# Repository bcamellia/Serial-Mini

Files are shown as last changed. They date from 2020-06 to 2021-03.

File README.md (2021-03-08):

Not actively developing, still wish to revisit at some point.

Serial Mini is an original rework of my PS/2 mini keyboard to further reduce input latency. It sends keystrokes using RS232 at up to a 115k baud rate. The keystrokes are processed and registered by a Linux kernel driver. The driver first converts a TTY line into a serial port object, connects the serial keyboard, and registers keystrokes using an interrupt. Using this method, I could achieve a round-trip latency of up to ~0.5ms.

Features:
* Bootloader support (in-development)
* Integrated MAX232 (in-development)
* Hardware based switch debouncing
* RBG Backlighting with controls (in-development)

To-do:
* Remove unused libraries
* Double check connections
* Add measurements and example video
* Write firmware without using CCS

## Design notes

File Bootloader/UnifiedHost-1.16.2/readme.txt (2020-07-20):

# README	General information
* Unified Bootloader Host Application 
- Used with the MCC Bootloader Generated Software Library for 8-bit or 16-bit MCU devices, or the 32-bit AN1388 bootloader.
- The graphical front-end of the 8-bit, 16-bit and 32-bit Bootloader project.

# Support
Email: MCC_Support@microchip.com
This application requires the Java 1.8 runtime.
Users of Microchip products can receive assistance through several channels:

 - Distributor or Representative
 - Local Sales Office
 - Field Application Engineer (FAE)
 - Technical Support

Customers should contact their distributor, representative or Field Application Engineer (FAE) for support.
Local sales offices are also available to help customers.
A listing of sales offices and locations may be found on the [Microchip web site][3].

Technical support is available through the [Microchip web site][4].

# CHANGELOG	A detailed changelog, intended for programmers
v 0.1.9:	Added readme, added logger, added checksum support to PIC32; added handling for record type 0x05 (currently ignored)
v 0.1.10:	Internal release
v 0.1.11:	Internal release
v 0.1.14:	Added PIC32 CRC bytes used at end of packets. Added Erase feature to USB PIC32 command chain. Extended Timeouts added support for 24-bit packet length.
v 0.1.15:	Fixed bug in PIC16 erase being half expected length during command chain. Added support for larger PIC18 device checksum commands, appending over previous Access Key bytes.
v 1.0.0:	Release version to support PIC24 family of devices. Added beta support for AVR devices.
v 1.15.0:   Release version to support dsPIC33 family of devices. Release support for AVR devices.
v 1.15.1:   Fixed bugs to support PIC-IOT WG Development Board, phantom byte for degenerate blocks and restrict data packet size to MAX_PACKET_SIZE - HEADER_SIZE.
v 1.16.1:   Updated HID4JAVA library used for USB communication. Updates to AVR support to support MCC generated code. Extended PIC32 timeout(s) to 20s (from 8) UDP, USB
v 1.16.2:   32-bit devices no longer wait for responds from Reset Command. Bugfixes for 16-bit support: 1) Self Verify issue with larger parts with 2) no report, 3) End Address corruption on read properties, 4) Exception thrown on UART disconnect.

# NEWS	A basic changelog, intended for users
-Incremented version information; see Changelog
-Added readme file on release of version: 0.1.14
-Added Checksum support for PIC32
-Bug fixes, Added Release Notes v 0.1.15 along with readme file. Added support for up to 32-bit checksum value calculation.
-Added Synch Byte expectation to AVR packet support.
-Fixed Typo in Help-->About text which indicated incorrect Utility version
-Added logger support requires launching from command prompt with below text:
* -Djava.util.logging.config.file="C:\<DirectoryLocation>"

i.e.: To Launch from Command Prompt
>java -Djava.util.logging.config.file="<Drive: e.g. C>:\<MyDirectory>\<UnifiedHost-version>\logging.properties" -jar UnifiedHost-<version>.jar

# INSTALL	Installation instructions
Installation of Java JRE

# COPYING / LICENSE	Copyright and licensing information
See LICENSE.txt for licensing information.

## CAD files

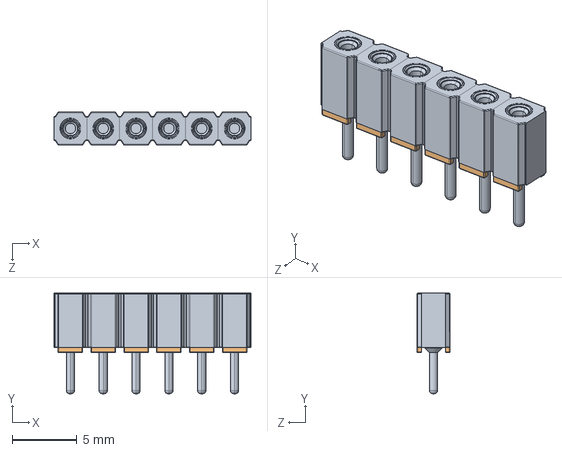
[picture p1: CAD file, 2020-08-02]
Hardware/models/801-xx-006-10-012000.STEP
15.2 x 7.78 x 2.54 mm

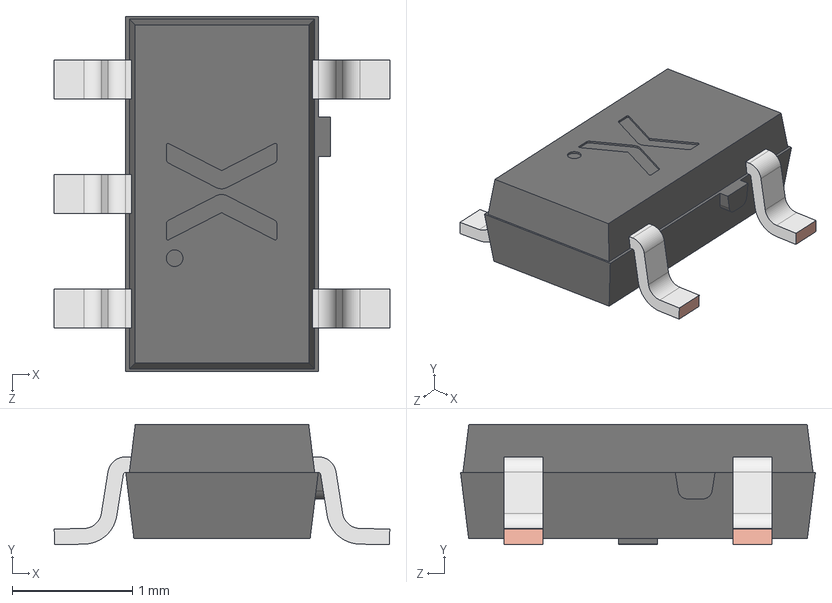
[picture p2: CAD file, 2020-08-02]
Hardware/models/SOT753.step
2.79 x 1.00 x 2.95 mm
SOT753 Lower mold body
SOT753 Lead x 5
SOT753 Upper mold body

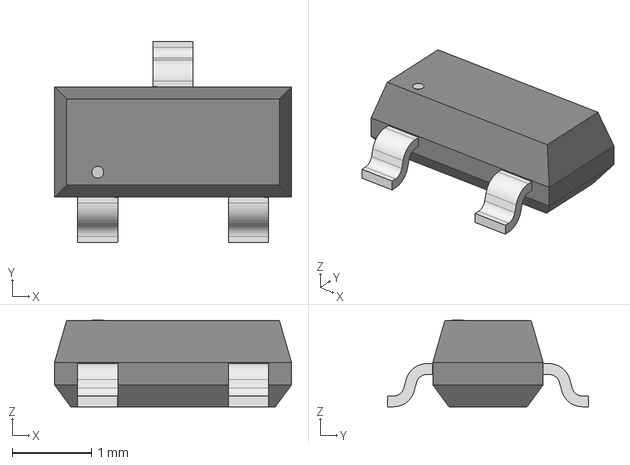
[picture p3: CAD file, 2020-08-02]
Hardware/models/SOT23_INF.step
3.00 x 2.54 x 1.09 mm

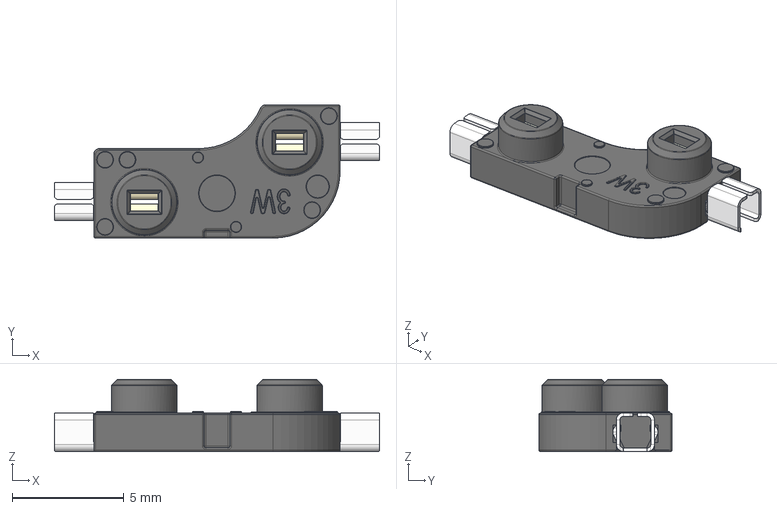
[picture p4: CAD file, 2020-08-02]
Hardware/models/Kailh Hotswap MX v22.step
14.5 x 5.95 x 3.22 mm

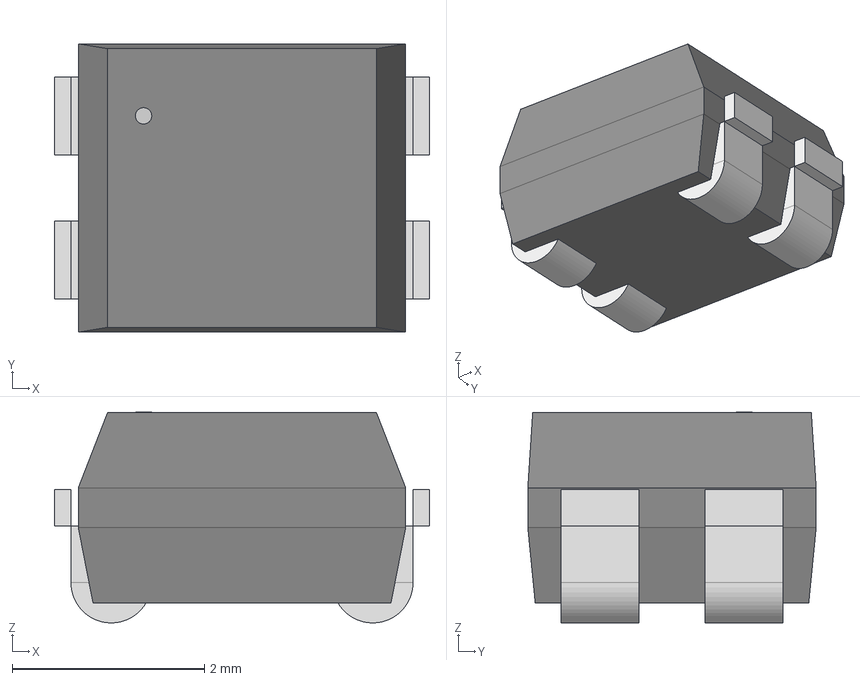
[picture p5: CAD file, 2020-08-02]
Hardware/models/BOX_7R3R3.step
3.90 x 3.00 x 2.19 mm

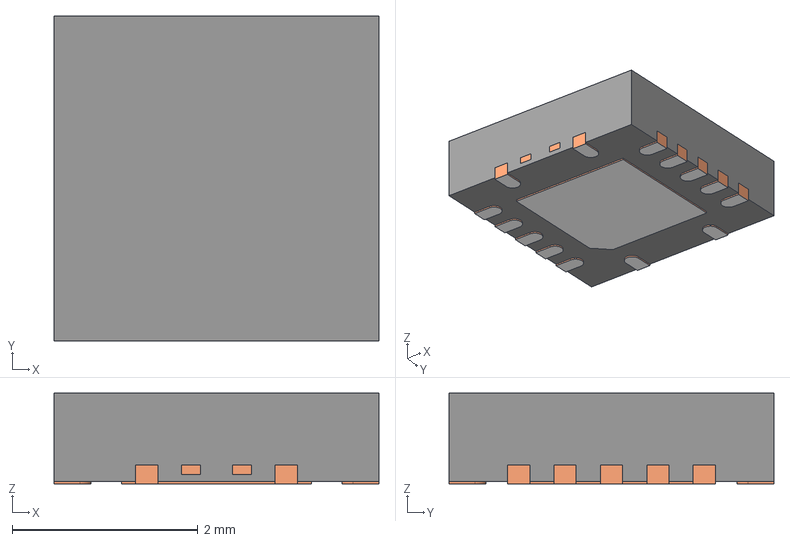
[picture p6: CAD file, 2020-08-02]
Hardware/models/RGY0014A.stp
3.50 x 3.50 x 0.975 mm
BODY-QFN
FRAME-RWA0014A
PIN1-ID

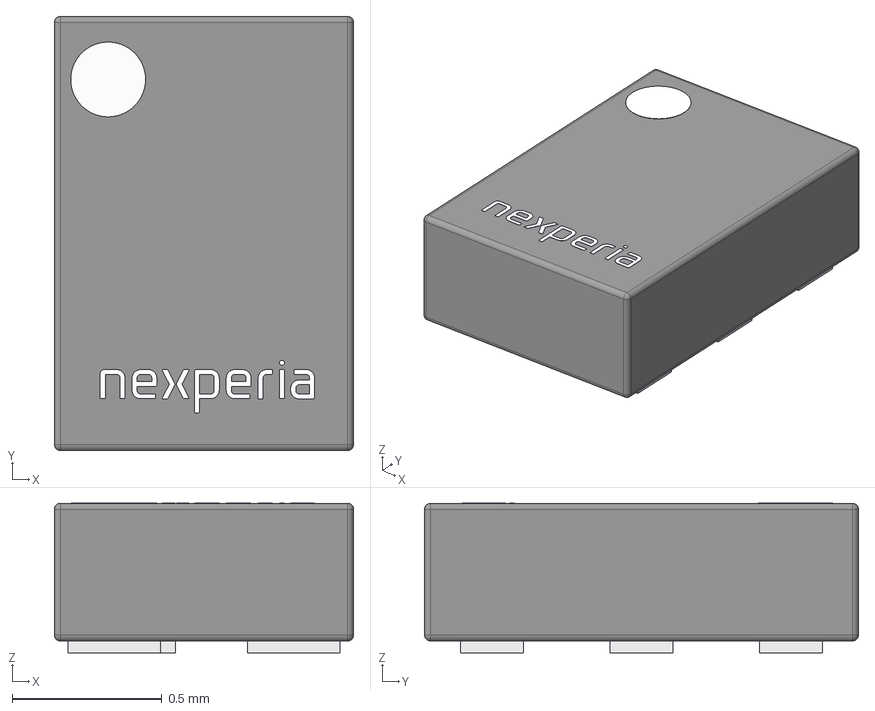
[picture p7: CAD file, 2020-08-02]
Hardware/models/Nexperia_-_PRTR5V0U2F,115.step
1.00 x 1.45 x 0.501 mm
Boady
Leads
Nexperia
circle

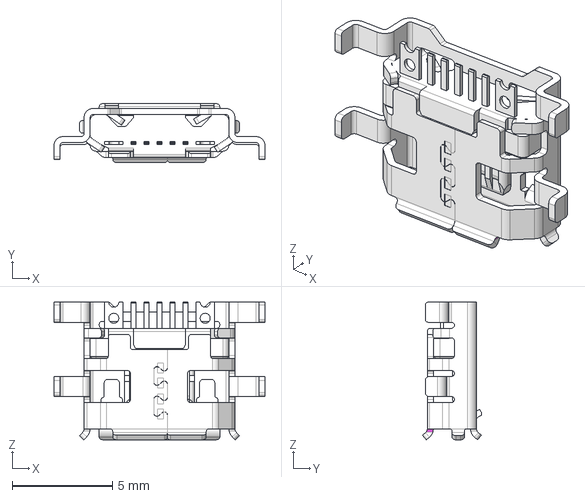
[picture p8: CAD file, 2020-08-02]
Hardware/models/10103593-0001lf.stp
10.5 x 2.94 x 6.85 mm

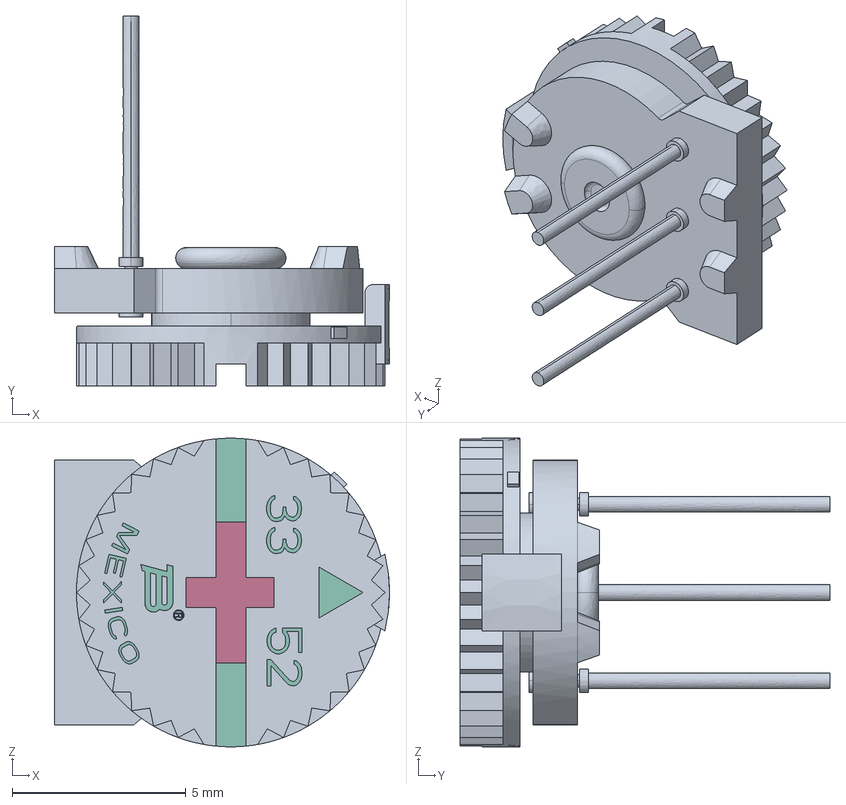
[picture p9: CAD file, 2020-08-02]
Hardware/models/3352T001XXX.stp
9.65 x 10.7 x 8.89 mm

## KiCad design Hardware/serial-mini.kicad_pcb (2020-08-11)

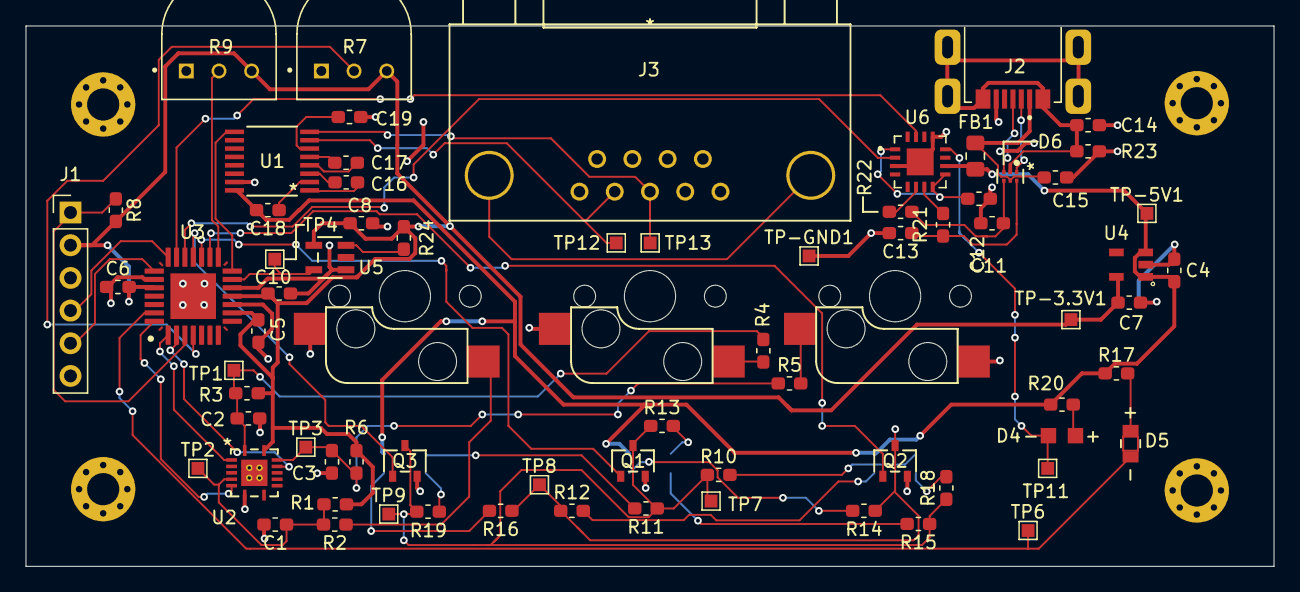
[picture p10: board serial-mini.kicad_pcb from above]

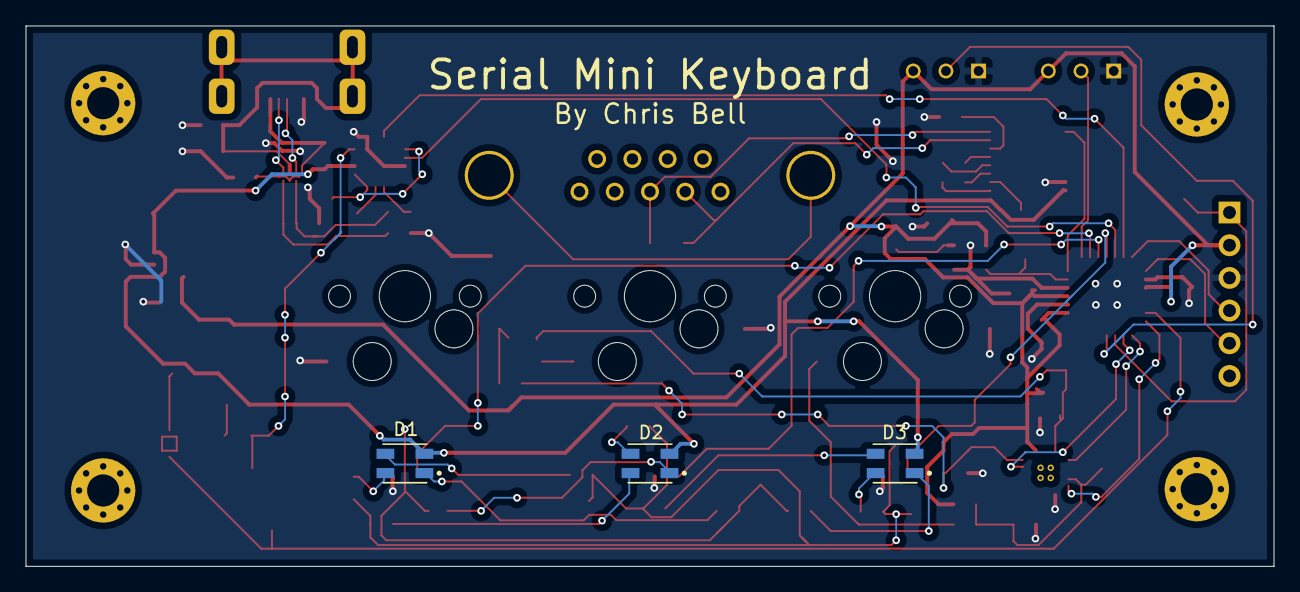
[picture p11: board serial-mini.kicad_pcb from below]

Board: 4 copper layers, 97.0 x 42.0 mm, 82 parts (3 on the bottom side), 58 nets.

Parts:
C1, C2, C3, C15: 10nF; C_0603_1608Metric_Pad1.05x0.95mm_HandSolder
C4, C7: 1UF; C_0603_1608Metric_Pad1.05x0.95mm_HandSolder
C5, C6, C8, C10: 0.1UF; C_0603_1608Metric_Pad1.05x0.95mm_HandSolder
C11: 0.1uF; C_0603_1608Metric_Pad1.05x0.95mm_HandSolder
C12, C13: 47pF; C_0603_1608Metric_Pad1.05x0.95mm_HandSolder
C14: 4.7nF; C_0603_1608Metric_Pad1.05x0.95mm_HandSolder
C16, C17, C18, C19: 1uF; C_0603_1608Metric_Pad1.05x0.95mm_HandSolder
D1, D2, D3: CLVBA-FKA; SOL150P350X210-4N
D4: LTST-C171KSKT; DIOC200X125X110
D5: VAOL-S8WR4
D6: PRTR5V0U2F,115; Nexperia-SOT886-11_2018-0-MFG
FB1: MI0805K601R; R_0805_2012Metric_Pad1.15x1.40mm_HandSolder
H1, H2, H3, H4: MountingHole; MountingHole_2.5mm_Pad_Via
J1: 801-47-006-10-012000; PICKITv3
J2: 10103593-0001LF; AMPHENOL_10103593-0001LF
J3: 3-106505-2
Q1, Q2, Q3: IRLML2060; IRLML2060TRPBF
R1, R3, R6, R8, R24: 10k; R_0603_1608Metric_Pad1.05x0.95mm_HandSolder
R2, R4, R5: 1k; R_0603_1608Metric_Pad1.05x0.95mm_HandSolder
R7, R9: 3352T-1-103LF; TRIM_3352T-1-103LF
R10, R11, R13, R15, R17, R18, R19: 100; R_0603_1608Metric_Pad1.05x0.95mm_HandSolder
R12, R14, R16, R20: 150; R_0603_1608Metric_Pad1.05x0.95mm_HandSolder
R21, R22: 27; R_0603_1608Metric_Pad1.05x0.95mm_HandSolder
R23: 1M; R_0603_1608Metric_Pad1.05x0.95mm_HandSolder
S1, S2, S3: KAILH_HOT_SWAP; Kailh_MX_Socket
TP1, TP2, TP3, TP4, TP6, TP7, TP8, TP9, TP11, TP12, TP13: TestPoint; TestPoint_Pad_1.0x1.0mm
TP-3.3V1, TP-5V1: TestPoint; TestPoint_Pad_1.0x1.0mm
TP-GND1: TestPoint; TestPoint_Pad_1.0x1.0mm
U1: MAX232ECPWR
U2: SN74AHC14RGYR
U3: DSPIC33CK64MP102; ‎DSPIC33CK32MP102
U4: MIC5504-3.3YM5-TR; MIC5504
U5: SIT2001BI-S2-33S-100.000000D
U6: FT230XQ-R; FT230XQ

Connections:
+3V3: C5.2, C6.2, C7.1, C8.2, C10.2, J1.VCC, R1.2, R3.1, R6.1, R7.3, R8.2, R9.3, R24.2, TP-3.3V1.1, U2.14, U3.AVDD, U3.VDD, U4.5, U5.4
+5V: C4.1, C18.2, D1.2, D2.2, D3.2, FB1.2, R17.1, R20.1, TP-5V1.1, U1.16, U4.1, U4.3, U6.10
/Backlight/2V@60mA: Q1.3, Q3.3, R10.1, R11.1, R13.1, R15.1, R18.1, R19.1, TP7.1, TP9.1
/Backlight/3.1V@60mA: Q2.3, R12.1, R14.1, R16.1, TP8.1
/Blue: Q3.1, U3.RB5
/Brightness: R7.2, U3.RA0
/Green: Q1.1, U3.RB4
/Hue: R9.2, U3.RB2
/MCLR: J1.MCLR, R8.1, U3.MCLR
/OSCO: TP4.1, U3.RB0, U5.5
/PGC: J1.PGC, U3.RB9
/PGD: J1.PGD, U3.RB8
/RX-Serial-Port: U1.9, U3.RB1
/Red: Q2.1, U3.RB3
/S1: U2.6, U3.RB13
/S2: U2.12, U3.RB15
/S3: U2.2, U3.RB14
/Status: D5.1, TP6.1, U3.RB12
/TTL to RS232 Converter/RS232-RX: J3.2, TP12.1, U1.7
/TTL to RS232 Converter/RS232-TX: J3.3, TP13.1, U1.8
/UART-RX: U3.RB6, U6.2
/UART-TX: U3.RB7, U6.15
/USB to UART/3V@20mA: D4.-, TP11.1, U6.12
/USB to UART/D+: D6.3, J2.3
/USB to UART/D-: D6.1, J2.2
/USB to UART/Shield: C14.2, D6.2, J2.S1, J2.S2, J2.S3, R23.1
/USB to UART/VUSB: C15.2, D6.5, FB1.1, J2.1
GND: C1.2, C2.1, C3.1, C4.2, C5.1, C6.1, C7.2, C8.1, C10.1, C11.2, C12.1, C13.2, C14.1, C15.1, C19.2, J1.GND, J2.5, Q1.2, Q2.2, Q3.2, R7.1, R9.1, R23.2, S1.1, S2.1, S3.2, TP-GND1.1, U1.15, U2.7, U3.AVSS, U3.PAD, U3.VSS, U4.2, U5.1, U6.3, U6.13, U6.17
unnamed: C1.1, R1.1, R2.2, TP2.1, U2.5
unnamed: C2.2, R3.2, R4.2, TP1.1, U2.1
unnamed: C3.2, R5.1, R6.2, TP3.1, U2.13
unnamed: C11.1, U6.1, U6.8, U6.9
unnamed: C12.2, D6.4, R22.2
unnamed: C13.1, D6.6, R21.2
unnamed: C16.1, U1.3
unnamed: C16.2, U1.1
unnamed: C17.1, U1.5
unnamed: C17.2, U1.4
unnamed: C18.1, U1.2
unnamed: C19.1, U1.6
unnamed: D1.1, R12.2
unnamed: D1.3, R10.2
unnamed: D1.4, R18.2
unnamed: D2.1, R14.2
unnamed: D2.3, R13.2
unnamed: D2.4, R15.2
unnamed: D3.1, R16.2
unnamed: D3.3, R11.2
unnamed: D3.4, R19.2
unnamed: D4.+, R20.2
unnamed: D5.2, R17.2
unnamed: J3.10, J3.11
unnamed: R2.1, S1.2
unnamed: R4.1, S2.2
unnamed: R5.2, S3.1
unnamed: R21.1, U6.7
unnamed: R22.1, U6.6
unnamed: R24.1, U5.3

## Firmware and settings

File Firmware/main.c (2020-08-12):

/**
  Generated main.c file from MPLAB Code Configurator

  @Company
    Microchip Technology Inc.

  @File Name
    main.c

  @Summary
    This is the generated main.c using PIC24 / dsPIC33 / PIC32MM MCUs.

  @Description
    This source file provides main entry point for system initialization and application code development.
    Generation Information :
        Product Revision  :  PIC24 / dsPIC33 / PIC32MM MCUs - 1.168.0
        Device            :  dsPIC33CK32MP102
    The generated drivers are tested against the following:
        Compiler          :  XC16 v1.50
        MPLAB 	          :  MPLAB X v5.40
*/

/*
    (c) 2020 Microchip Technology Inc. and its subsidiaries. You may use this
    software and any derivatives exclusively with Microchip products.

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
    IN NO EVENT WILL MICROCHIP BE LIABLE FOR ANY INDIRECT, SPECIAL, PUNITIVE,
    INCIDENTAL OR CONSEQUENTIAL LOSS, DAMAGE, COST OR EXPENSE OF ANY KIND
    WHATSOEVER RELATED TO THE SOFTWARE, HOWEVER CAUSED, EVEN IF MICROCHIP HAS
    BEEN ADVISED OF THE POSSIBILITY OR THE DAMAGES ARE FORESEEABLE. TO THE
    FULLEST EXTENT ALLOWED BY LAW, MICROCHIP'S TOTAL LIABILITY ON ALL CLAIMS IN
    ANY WAY RELATED TO THIS SOFTWARE WILL NOT EXCEED THE AMOUNT OF FEES, IF ANY,
    THAT YOU HAVE PAID DIRECTLY TO MICROCHIP FOR THIS SOFTWARE.

    MICROCHIP PROVIDES THIS SOFTWARE CONDITIONALLY UPON YOUR ACCEPTANCE OF THESE
    TERMS.
*/

/**
  Section: Included Files
*/
#include "mcc_generated_files/system.h"
#include "mcc_generated_files/pin_manager.h"
#include "mcc_generated_files/clock.h"
#define FCY 80000000UL
#include <libpic30.h>

/*
                         Main application
 */
int main(void)
{
    // initialize the device
    SYSTEM_Initialize();
    while (1)
    {
        Status_SetLow();
        __delay_ms(1000);
        Status_SetHigh();
        __delay_ms(1000);
    }
    return 1; 
}
/**
 End of File
*/

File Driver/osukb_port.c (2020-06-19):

// SPDX-License-Identifier: GPL-2.0-only
/*
 * Input device TTY line discipline
 *
 * Copyright (c) 1999-2002 Vojtech Pavlik
 *
 * This is a module that converts a tty line into a much simpler
 * 'serial io port' abstraction that the input device drivers use.
 * This is the same as serport.c except uses the default TTY line discipline
 * since we are an osu! keyboard.
 */


#include <linux/uaccess.h>
#include <linux/kernel.h>
#include <linux/sched.h>
#include <linux/slab.h>
#include <linux/module.h>
#include <linux/init.h>
#include <linux/serio.h>
#include <linux/tty.h>
#include <linux/compat.h>

MODULE_AUTHOR("Vojtech Pavlik <vojtech@ucw.cz>");
MODULE_DESCRIPTION("Input device TTY line discipline");
MODULE_LICENSE("GPL");
MODULE_ALIAS_LDISC(N_TTY);

#define SERPORT_BUSY	1
#define SERPORT_ACTIVE	2
#define SERPORT_DEAD	3

struct serport {
	struct tty_struct *tty;
	wait_queue_head_t wait;
	struct serio *serio;
	struct serio_device_id id;
	spinlock_t lock;
	unsigned long flags;
};

/*
 * Callback functions from the serio code.
 */

static int serport_serio_write(struct serio *serio, unsigned char data)
{
	struct serport *serport = serio->port_data;
	return -(serport->tty->ops->write(serport->tty, &data, 1) != 1);
}

static int serport_serio_open(struct serio *serio)
{
	struct serport *serport = serio->port_data;
	unsigned long flags;

	spin_lock_irqsave(&serport->lock, flags);
	set_bit(SERPORT_ACTIVE, &serport->flags);
	spin_unlock_irqrestore(&serport->lock, flags);

	return 0;
}


static void serport_serio_close(struct serio *serio)
{
	struct serport *serport = serio->port_data;
	unsigned long flags;

	spin_lock_irqsave(&serport->lock, flags);
	clear_bit(SERPORT_ACTIVE, &serport->flags);
	spin_unlock_irqrestore(&serport->lock, flags);
}

/*
 * serport_ldisc_open() is the routine that is called upon setting our line
 * discipline on a tty. It prepares the serio struct.
 */

static int serport_ldisc_open(struct tty_struct *tty)
{
	struct serport *serport;

	if (!capable(CAP_SYS_ADMIN))
		return -EPERM;

	serport = kzalloc(sizeof(struct serport), GFP_KERNEL);
	if (!serport)
		return -ENOMEM;

	serport->tty = tty;
	spin_lock_init(&serport->lock);
	init_waitqueue_head(&serport->wait);

	tty->disc_data = serport;
	tty->receive_room = 256;
	set_bit(TTY_DO_WRITE_WAKEUP, &tty->flags);

	return 0;
}

/*
 * serport_ldisc_close() is the opposite of serport_ldisc_open()
 */

static void serport_ldisc_close(struct tty_struct *tty)
{
	struct serport *serport = (struct serport *) tty->disc_data;

	kfree(serport);
}

/*
 * serport_ldisc_receive() is called by the low level tty driver when characters
 * are ready for us. We forward the characters and flags, one by one to the
 * 'interrupt' routine.
 */

static void serport_ldisc_receive(struct tty_struct *tty, const unsigned char *cp, char *fp, int count)
{
	struct serport *serport = (struct serport*) tty->disc_data;
	unsigned long flags;
	unsigned int ch_flags = 0;
	int i;

	spin_lock_irqsave(&serport->lock, flags);

	if (!test_bit(SERPORT_ACTIVE, &serport->flags))
		goto out;

	for (i = 0; i < count; i++) {
		if (fp) {
			switch (fp[i]) {
			case TTY_FRAME:
				ch_flags = SERIO_FRAME;
				break;

			case TTY_PARITY:
				ch_flags = SERIO_PARITY;
				break;

			default:
				ch_flags = 0;
				break;
			}
		}

		serio_interrupt(serport->serio, cp[i], ch_flags);
	}

out:
	spin_unlock_irqrestore(&serport->lock, flags);
}

/*
 * serport_ldisc_read() just waits indefinitely if everything goes well.
 * However, when the serio driver closes the serio port, it finishes,
 * returning 0 characters.
 */

static ssize_t serport_ldisc_read(struct tty_struct * tty, struct file * file, unsigned char __user * buf, size_t nr)
{
	struct serport *serport = (struct serport*) tty->disc_data;
	struct serio *serio;

	if (test_and_set_bit(SERPORT_BUSY, &serport->flags))
		return -EBUSY;

	serport->serio = serio = kzalloc(sizeof(struct serio), GFP_KERNEL);
	if (!serio)
		return -ENOMEM;

	strlcpy(serio->name, "Serial port", sizeof(serio->name));
	snprintf(serio->phys, sizeof(serio->phys), "%s/serio0", tty_name(tty));
	serio->id = serport->id;
	serio->id.type = SERIO_RS232;
	serio->write = serport_serio_write;
	serio->open = serport_serio_open;
	serio->close = serport_serio_close;
	serio->port_data = serport;
	serio->dev.parent = tty->dev;

	serio_register_port(serport->serio);
	printk(KERN_INFO "osukb_port: Serial port %s\n", tty_name(tty));

	wait_event_interruptible(serport->wait, test_bit(SERPORT_DEAD, &serport->flags));
	serio_unregister_port(serport->serio);
	serport->serio = NULL;

	clear_bit(SERPORT_DEAD, &serport->flags);
	clear_bit(SERPORT_BUSY, &serport->flags);

	return 0;
}

static void serport_set_type(struct tty_struct *tty, unsigned long type)
{
	struct serport *serport = tty->disc_data;

	serport->id.proto = type & 0x000000ff;
	serport->id.id    = (type & 0x0000ff00) >> 8;
	serport->id.extra = (type & 0x00ff0000) >> 16;
}

/*
 * serport_ldisc_ioctl() allows to set the port protocol, and device ID
 */

static int serport_ldisc_ioctl(struct tty_struct *tty, struct file *file,
			       unsigned int cmd, unsigned long arg)
{
	if (cmd == SPIOCSTYPE) {
		unsigned long type;

		if (get_user(type, (unsigned long __user *) arg))
			return -EFAULT;

		serport_set_type(tty, type);
		return 0;
	}

	return -EINVAL;
}

#ifdef CONFIG_COMPAT
#define COMPAT_SPIOCSTYPE	_IOW('q', 0x01, compat_ulong_t)
static long int serport_ldisc_compat_ioctl(struct tty_struct *tty,
				       struct file *file,
				       unsigned int cmd, unsigned long arg)
{
	if (cmd == COMPAT_SPIOCSTYPE) {
		void __user *uarg = compat_ptr(arg);
		compat_ulong_t compat_type;

		if (get_user(compat_type, (compat_ulong_t __user *)uarg))
			return -EFAULT;

		serport_set_type(tty, compat_type);
		return 0;
	}

	return -EINVAL;
}
#endif

static int serport_ldisc_hangup(struct tty_struct *tty)
{
	struct serport *serport = (struct serport *) tty->disc_data;
	unsigned long flags;

	spin_lock_irqsave(&serport->lock, flags);
	set_bit(SERPORT_DEAD, &serport->flags);
	spin_unlock_irqrestore(&serport->lock, flags);

	wake_up_interruptible(&serport->wait);
	return 0;
}

static void serport_ldisc_write_wakeup(struct tty_struct * tty)
{
	struct serport *serport = (struct serport *) tty->disc_data;
	unsigned long flags;

	spin_lock_irqsave(&serport->lock, flags);
	if (test_bit(SERPORT_ACTIVE, &serport->flags))
		serio_drv_write_wakeup(serport->serio);
	spin_unlock_irqrestore(&serport->lock, flags);
}

/*
 * The line discipline structure.
 */

static struct tty_ldisc_ops serport_ldisc = {
	.owner =	THIS_MODULE,
	.name =		"osu!_kb_input",
	.open =		serport_ldisc_open,
	.close =	serport_ldisc_close,
	.read =		serport_ldisc_read,
	.ioctl =	serport_ldisc_ioctl,
#ifdef CONFIG_COMPAT
	.compat_ioctl =	serport_ldisc_compat_ioctl,
#endif
	.receive_buf =	serport_ldisc_receive,
	.hangup =	serport_ldisc_hangup,
	.write_wakeup =	serport_ldisc_write_wakeup
};
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

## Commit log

2020-06-19 Add driver and firmware files
    [configuration.h]
2020-07-15 Start working on new schematic
    Cleaning up unused library symbols, adding symbols to single library
    [serial-mini.kicad_pcb, serial-mini.sch]
2020-07-15 Add RGB Leds
    Simplified design to 3 keys and added potentiometers
2020-07-17 Update schematic symbols
    Started adding schematic symbols to project specific library, mapping footprints to symbols
    [serial-mini.sch]
2020-07-20 Update symbols/footprints
    Linked most symbols to their datasheets, updated more footprint/symbol footprints.
    Also added status indicator LED
    [serial-mini.kicad_pcb, serial-mini.sch]
2020-07-20 Move design folder
    [serial-mini.kicad_pcb, serial-mini.sch]
2020-07-20 Add more labels
    Swapped some LEDs
    [serial-mini.sch]
2020-07-20 Add test points
    Swapped RGB LEDs, updated pin types to pass ERC, removed unused libraries/footprints
    [serial-mini.sch]
2020-07-20 Remove unused footprint references
2020-07-20 Update PCB
    [serial-mini.kicad_pcb]
2020-07-26 Try optimizing PCB layout
    [serial-mini.kicad_pcb, serial-mini.sch]
2020-07-26 Initial placement of footprints
    [serial-mini.kicad_pcb, serial-mini.sch]
2020-07-26 Begin routing
    [serial-mini.kicad_pcb]
2020-07-26 Continue routing
    [serial-mini.kicad_pcb, serial-mini.sch]
2020-07-26 Finish routing
    [serial-mini.kicad_pcb]
2020-07-26 Add missing courtyards
    [serial-mini.kicad_pcb, serial-mini.sch]
2020-07-27 Add EMI/ESD protection on USB port
    [Nexperia_-_PRTR5V0U2F,115.step, serial-mini.kicad_pcb, serial-mini.sch]
2020-07-27 Use hierarchical sheets
    Added MAX232 also
    [backlight.sch, debounce.sch, oscillator.sch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]
2020-07-28 Complete new schematic
    Added MAX232 and fixed test points on switches
    [backlight.sch, debounce.sch, oscillator.sch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]
2020-07-28 Add more net labels
    Begin redesigning PCB again
    [debounce.sch, oscillator.sch, rs232-converter.sch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]
2020-07-28 Add missing power regulator .sch
    [power-regulator.sch]
2020-08-02 Complete initial routing
    [rs232-converter.sch, serial-mini.kicad_pcb, usb-uart.sch]
2020-08-02 Fix incorrect footprints
    Fixed incorrect footprint for IRLML2060 and updated LED values to use CLVBA-FKA.
    Also started deleting unneccessary test points
    [backlight.sch, oscillator.sch, serial-mini.kicad_pcb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]
2020-08-02 Fix DRC errors
    Courtyard overlaps
    [serial-mini.kicad_pcb]
2020-08-02 Adjust all track/text widths
    [serial-mini.kicad_pcb]
2020-08-02 Finish placing footprint labels
    [sLD09S33E4GX00LF.stp, serial-mini.kicad_pcb]
2020-08-02 Fix faulty debounce circuit
    Used wrong value resistor/misplaced on each switch.
    Also adjusted value of RC circuits for a time constant of 1 microsecond (was 1 millisecond before)
    [10103593-0001lf.stp, 3352T001XXX.stp, BOX_7R3R3.step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]
2020-08-02 Fix weird routing
    [oscillator.sch, serial-mini.kicad_pcb]
2020-08-02 Add 3D file references
    Generated first build
    [801-xx-006-10-012000.STEP, SOT753.step, sLD09S33E4GX00LF.stp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]
2020-08-03 Fix USB through holes
    Cleaned-up unused files
    [serial-mini.kicad_pcb]
2020-08-03 Add BOM
    [backlight.sch, rs232-converter.sch, serial-mini.kicad_pcb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]
2020-08-11 Fix PRTR5V0U2F footprint
    Footprint was flipped wrong way on PCB, also removed BOM folder since it messed up Linguist
    [backlight.sch, regulator.sch, serial-mini.kicad_pcb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]
2020-08-12 Add new firmware project
    [configuration.h]

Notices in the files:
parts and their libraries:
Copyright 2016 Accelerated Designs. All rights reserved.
